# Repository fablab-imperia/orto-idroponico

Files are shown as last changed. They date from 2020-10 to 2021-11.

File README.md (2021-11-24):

# Orto idroponico
> Sistema di controllo per coltivazione idroponica che consente circolazione dell'acqua e parziale correzione dei valori di PH e conducibilità della stessa.

*Read this in other languages: [English :uk: :us:](README.EN.md).*

# Sommario
- [Componenti](#componenti)
- [Schema di Montaggio](#schema-di-montaggio)
- [Configurazione](#configurazione-e-calibrazione)
- [Compilazione del Software](#compilazione-del-software)
  - [Arduino IDE](#arduino-ide)
  - [Visual Studio Code e PlatformIO](#visual-studio-code-e-platformio)
- [Utilizzo e Interfaccia Grafica](#utilizzo-e-interfaccia-grafica)
- [Licenza](#licenza)

# Componenti
Struttura e pompe:
- x2 pompe peristaltiche 12V DC (per fertilizzante e acido)
- Pompa di ricircolo dell'acqua 230V AC (ad esempio per acquari)
- Tubi PVC e raccordi
- Scatola di derivazione (sufficientemente grande da proteggere l'intera elettronica)
- Struttura di sostegno, contenitori per acqua, acido e fertilizzante
- Eventuale interruttore generale

Elettronica:
- ESP32 NodeMCU Development Board
- Sonda pH e relativo modulo
- Sensore Temperatura DS18B20 e relativo modulo
- Sensore Conducibilità e relativo modulo
- LM2596 convertitore step-down
- Display LCD I2C 4x20 caratteri
- Convertitore di livelli logici bidirezionale
- Adafruit ADC ADS1115 (compatibile anche con ADS1015*)
- Modulo con due Relé a Stato Solido
- Modulo singolo Relé a Stato Solido HY-M285
- x2 transistor BC337-40 (o equivalenti)
- x2 resistori 680 Ω
- Alimentatore 12V DC
- PCB o altra soluzione di montaggio (es millefori)

*È necessario definire il tipo di ADC utilizzato nel file [/orto-controller-web/parameters.hpp](/orto-controller-web/parameters.hpp#L30)

Possono essere necessari anche altri componenti (cavi, viti...) e strumenti (trapano, saldatore...) utili alla realizzazione del progetto.

# Schema di Montaggio

I collegamenti ai pin sono definiti nel file `pinouts.hpp` e possono essere modificati opportunamente (prestando attenzione a non utilizzare impropriamente i pin riservati o con funzioni particolari, si veda il [pinout della scheda](https://raw.githubusercontent.com/fablab-imperia/orto-idroponico/main/pinouts/esp32-az-delivery.jpg) per i dettagli).

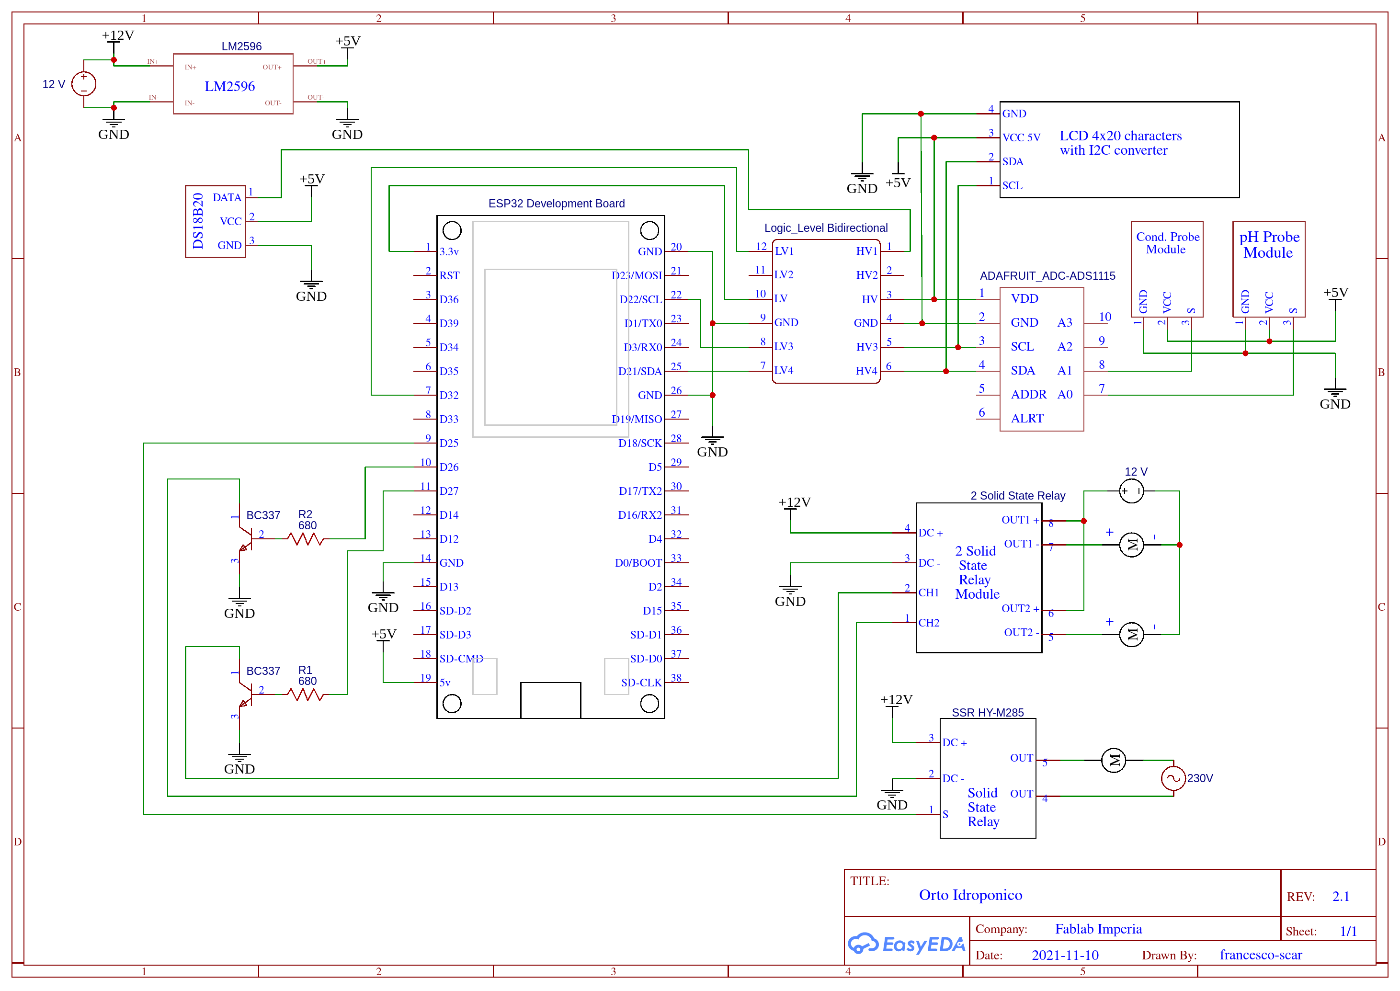
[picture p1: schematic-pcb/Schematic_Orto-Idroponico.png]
alt Orto Idroponico Schematic


# Configurazione e Calibrazione

Prima di procedere con la compilazione del software è necessario assegnare a `condCalibrationPoints[]` e `phCalibrationPoints[]` i valori per la calibrazione dei sensori.

Inoltre è possibile modificare i parametri principali dal file [parameters.hpp](https://github.com/fablab-imperia/orto-idroponico/blob/main/orto-controller-web/parameters.hpp) e i collegamenti con i pin della scheda dal file [pinouts.hpp](https://github.com/fablab-imperia/orto-idroponico/blob/main/orto-controller-web/pinouts.hpp)

# Compilazione del Software

## Arduino IDE

Per procedere con la compilazione mediante Arduino IDE è possibile procedere con i seguenti passaggi:
1. Installazione dell'[IDE di Arduino](https://www.arduino.cc/en/software)

2. Clonazione del repository
```
git clone https://github.com/fablab-imperia/orto-idroponico.git
```
3. Installazione delle dipendenze tramite Arduino Library Manager (selezionare *Sketch > Gestione Librerie* ) oppure scaricando i file zip dal sito di ogni libreria oppure copiando le librerie della cartella [libraries](https://github.com/fablab-imperia/orto-idroponico/tree/main/libraries):
  * [DallasTemperature](https://www.milesburton.com/Dallas_Temperature_Control_Library)
  * [OneWire](http://www.pjrc.com/teensy/td_libs_OneWire.html)
  * [LiquidCrystal I2C](https://github.com/marcoschwartz/LiquidCrystal_I2C)
  * [ArduinoJson](https://github.com/bblanchon/ArduinoJson)
  * [ESPAsyncWebServer](https://github.com/me-no-dev/ESPAsyncWebServer)
  * [AsyncTCP](https://github.com/me-no-dev/AsyncTCP)
  * [Adafruit_ADS1X15](https://github.com/adafruit/Adafruit_ADS1X15)

4. Installazione della scheda ESP32 nell'IDE:
   - a. Da *File > Preferenze > URL Gestore Schede Aggiuntive* aggiungere ```https://dl.espressif.com/dl/package_esp32_index.json```
   - b. Da *Strumenti > Schede > Gestore Schede* cercare ESP32 e installare la relativa scheda
   - c. Selezionare *ESP32 Dev Module* da *Strumenti > Schede*

5. Installare [ESP32 FS-plugin](https://github.com/me-no-dev/arduino-esp32fs-plugin) nell'ide di Arduino

6. Aprire il file [orto-controller-web/orto-controller-web.ino](https://github.com/fablab-imperia/orto-idroponico/blob/main/orto-controller-web/orto-controller-web.ino) nell'IDE di Arduino

7. Avviare la compilazione e caricare il programma sulla scheda (assicurarsi di aver selezionato la scheda e la porta seriale corretta dal menu *Strumenti*)

8. Caricare i file web sulla scheda da *Strumenti > ESP32 Sketch Data Upload*

## Visual Studio Code e PlatformIO

Per procedere con la compilazione mediante Visual Studio Code:
1. Installare [Visual Studio Code](https://code.visualstudio.com/)
2. Installare l'estensione [Platformio](https://platformio.org/install/ide?install=vscode)
3. Aprire la cartella orto-controller-web
4. Installare le librerie richieste
5. Avviare la compilazione  
6. Caricare i file web sulla scheda

# Utilizzo e Interfaccia Grafica
Dopo aver caricato correttamente il programma e i dati, la scheda crea una rete WiFi con SSID e password specificate [qui](https://github.com/fablab-imperia/orto-idroponico/blob/main/orto-controller-web/parameters.hpp#L22) (di default SSID `OrtoWeb` e password `OrtoWeb12345`).
Collegarsi con le credenziali corrette alla rete WiFi e, tramite un browser (es. Firefox, Chrome), connettersi all'indirizzo IP della scheda, stampato all'avvio sul monitor seriale (di default `192.168.4.1`).

Verrà visualizzata la seguente interfaccia grafica.

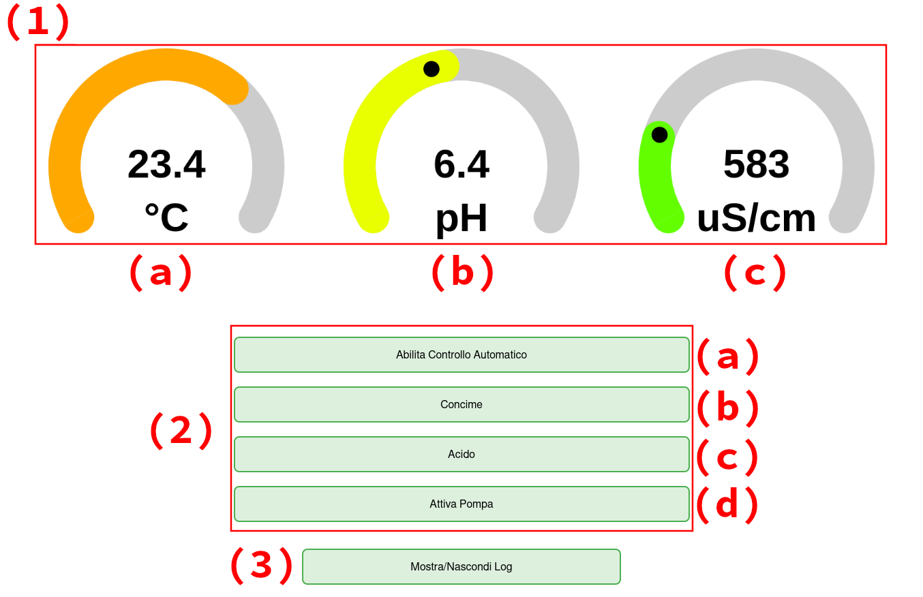
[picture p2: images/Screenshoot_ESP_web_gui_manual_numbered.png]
alt Manual Control Interface


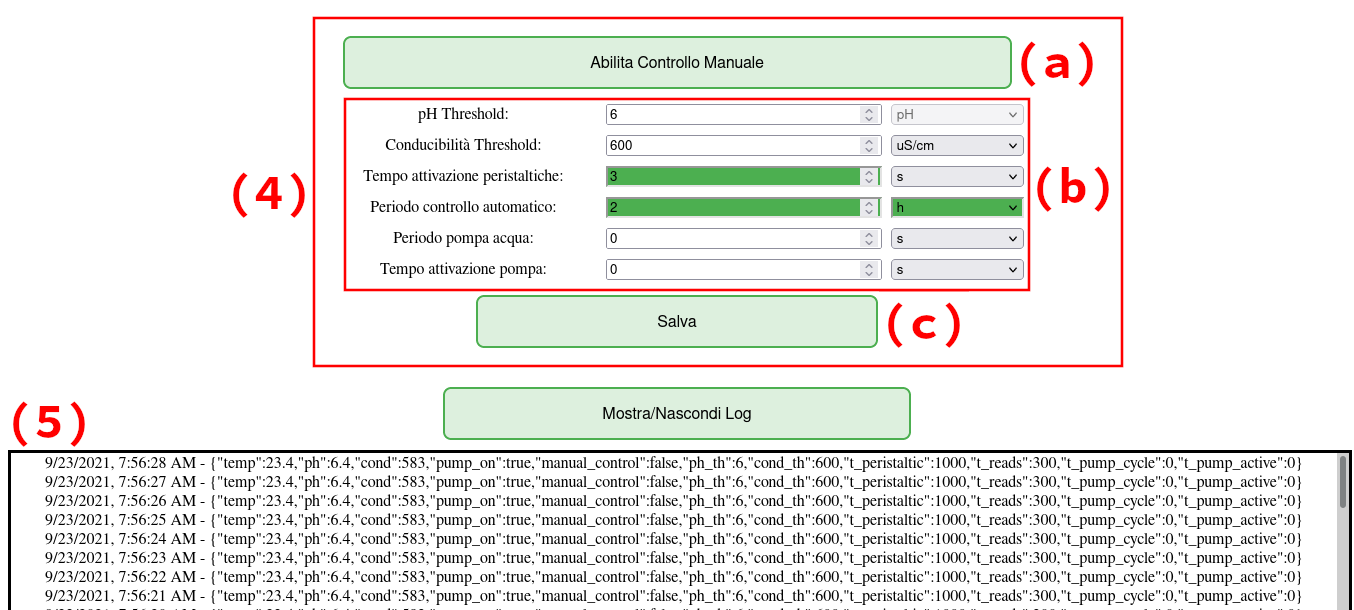
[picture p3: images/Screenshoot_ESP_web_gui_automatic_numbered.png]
alt Automatic Control Interface


L'interfaccia è composta dei seguenti elementi:

1. Indicatore sensori (i pallini neri negli indicatori *b* e *c* indicano il target attualmente impostato), il range dell'indicatore è impostato [qui](https://github.com/fablab-imperia/orto-idroponico/blob/main/orto-controller-web/data/main.js#L18) con i parametri *min* e *max*:
   * a. Temperatura dell'acqua (range indicatore: 0-35 °C)
   * b. pH dell'acqua (range indicatore: 0-14)
   * c. Conducibilita dell'acqua (range indicatore: 0-3000 uS/cm)

2. Pannello di controllo manuale (attivabile con pulsante 4.a)
   * a. Pulsante per abilitare il controllo automatico con i parametri definiti alla sezione (4); alla pressione questa sezione viene sostituita dalla sezione (4)
   * b. Attiva manualmente la pompa peristaltica del concime per la durata della pressione del pulsante (interrompe l'erogazione appena si rilascia il bottone)
   * c. Attiva manualmente la pompa peristaltica dell'acido (per la correzione del pH) per la durata della pressione del pulsante (interrompe l'erogazione appena si rilascia il bottone)
   * d. Attiva/Disattiva la pompa per il ricircolo dell'acqua, alla pressione commuta il suo stato e la sua funzione (da Attiva a Disattiva e viceversa)

3. Mostra o Nasconde i dati grezzi ricevuti dalla scheda, mostrati nella sezione (5) (di default sono nascosti)

4. Pannello di controllo automatico (attivabile con pulsante 2.a)
   * a. Pulsante per abilitare il controllo manuale, sospendento la correzione automatica di fertilizzante e pH e spegnendo la pompa di ricircolo; alla pressione questa sezione viene sostituita dalla sezione (2)
   * b. Parametri di configurazione del controllo automatico:
     * a. valore target del pH
     * b. valore target della conducibilità
     * c. durata di attivazione delle pompe di fertilizzante e acido in caso di correzione dei valori
     * d. tempo che intercorre tra due controlli e correzioni (attivazione pompe peristaltiche) successive
     * e. durata ciclo periodico di ricircolo dell'acqua (se posto a 0 la pompa sarà sempre attiva e il parametro *f* verrà ignorato)
     * f. tempo di attivazione della pompa per il ricircolo dell'acqua in ogni periodo definito al punto *e*
   * c. Il pulsante è normalmente disabilitato, viene attivato automaticamente quando si modifica uno o più dei precedenti parameteri (i parametri modificati vengono evidenziati in verde). Le modifiche dei parametri hanno effetto solo dopo il salvataggio. I dati salvati vengono mantenuti anche dopo lo spegnimento, perché memorizzati nella memoria EEPROM del controllore.

5. Log dei dati grezzi ricevuti dall scheda, la visualizzazione può essere abilitata e disabilitata con il pulsante (3)

I dati dei sensori e i parametri di stato (es controllo automatico/manuale, impostazioni salvate, attivazione manuale della pompa) vengono sincronizzati automaticamente in tempo reale su tutti i client connessi alla scheda.

## Licenza
Sistema di gestione orto idroponico Fablab Imperia

Copyright ©2021  Fablab Imperia, Francesco Scarrone, Stefano Semeria, Valerio Pace

This program is free software: you can redistribute it and/or modify
it under the terms of the GNU General Public License as published by
the Free Software Foundation, either version 3 of the License, or
(at your option) any later version.

This program is distributed in the hope that it will be useful,
but WITHOUT ANY WARRANTY; without even the implied warranty of
MERCHANTABILITY or FITNESS FOR A PARTICULAR PURPOSE.  See the
GNU General Public License for more details.

You should have received a copy of the GNU General Public License
along with this program.  If not, see <https://www.gnu.org/licenses/>.

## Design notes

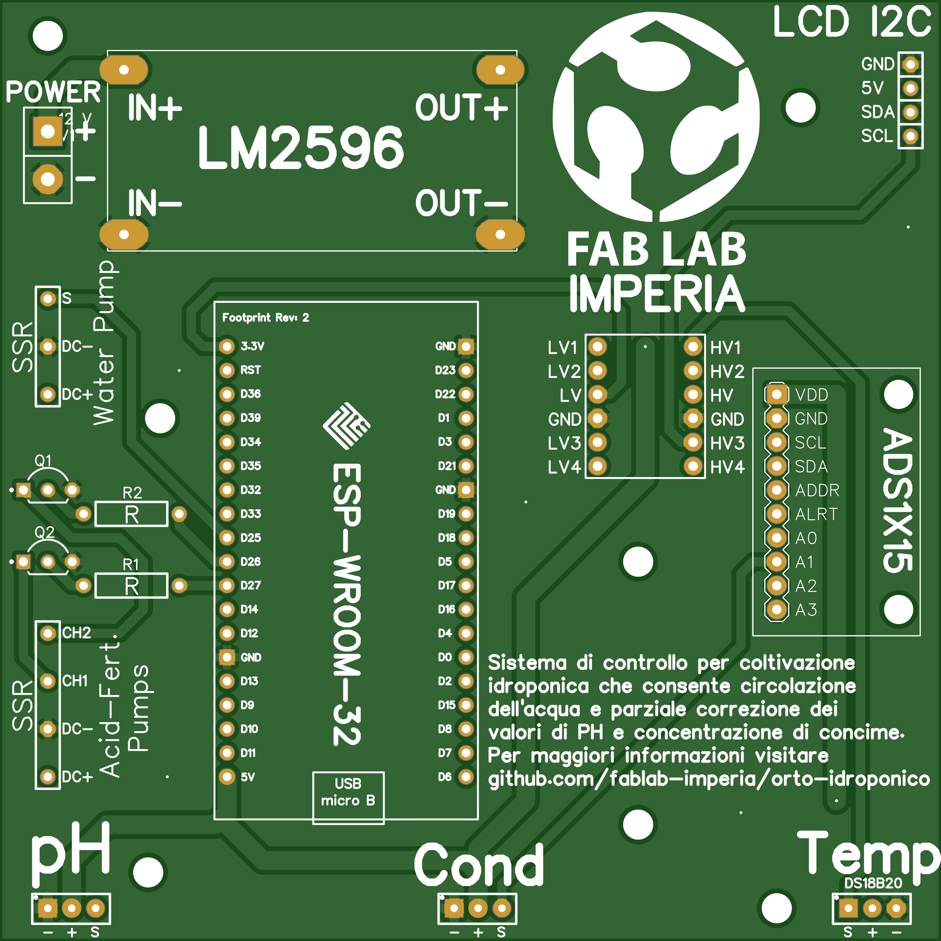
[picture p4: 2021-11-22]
schematic-pcb/PCB_top.png

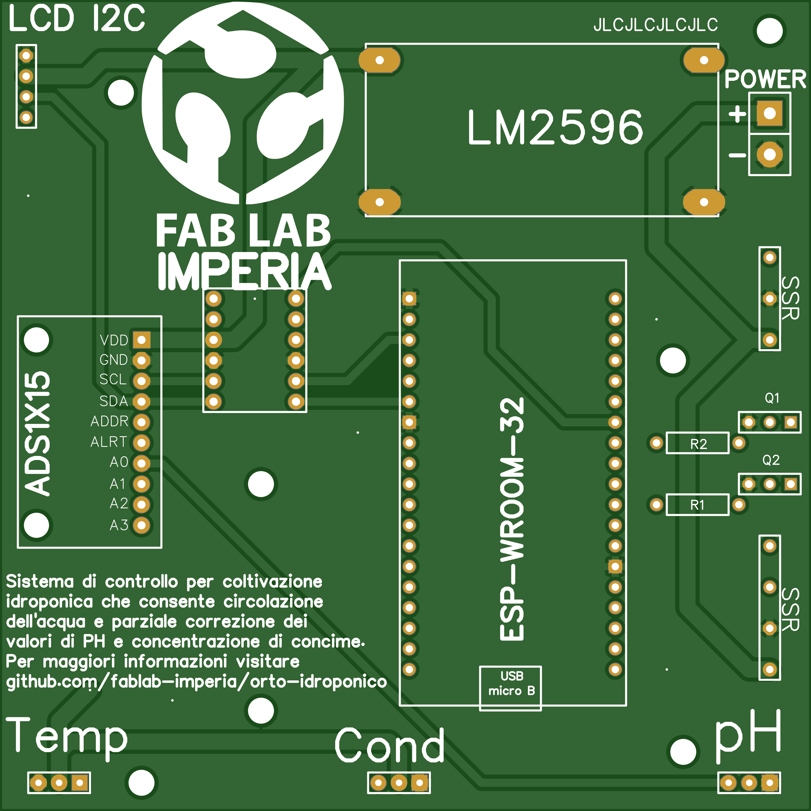
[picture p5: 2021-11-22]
schematic-pcb/PCB_bottom.png

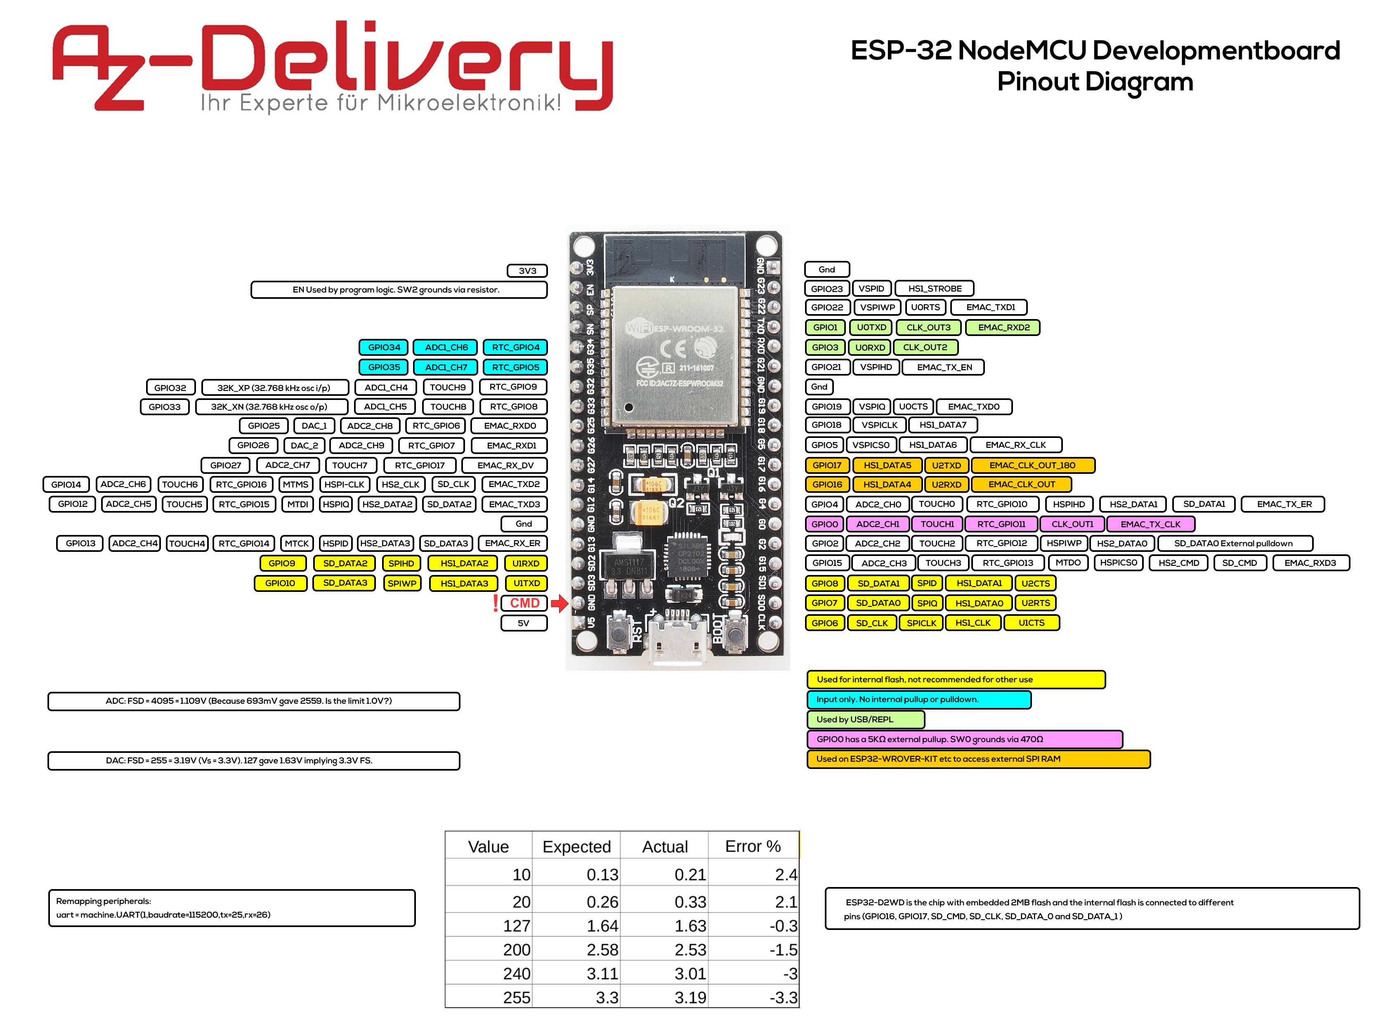
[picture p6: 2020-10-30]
pinouts/esp32-az-delivery.jpg

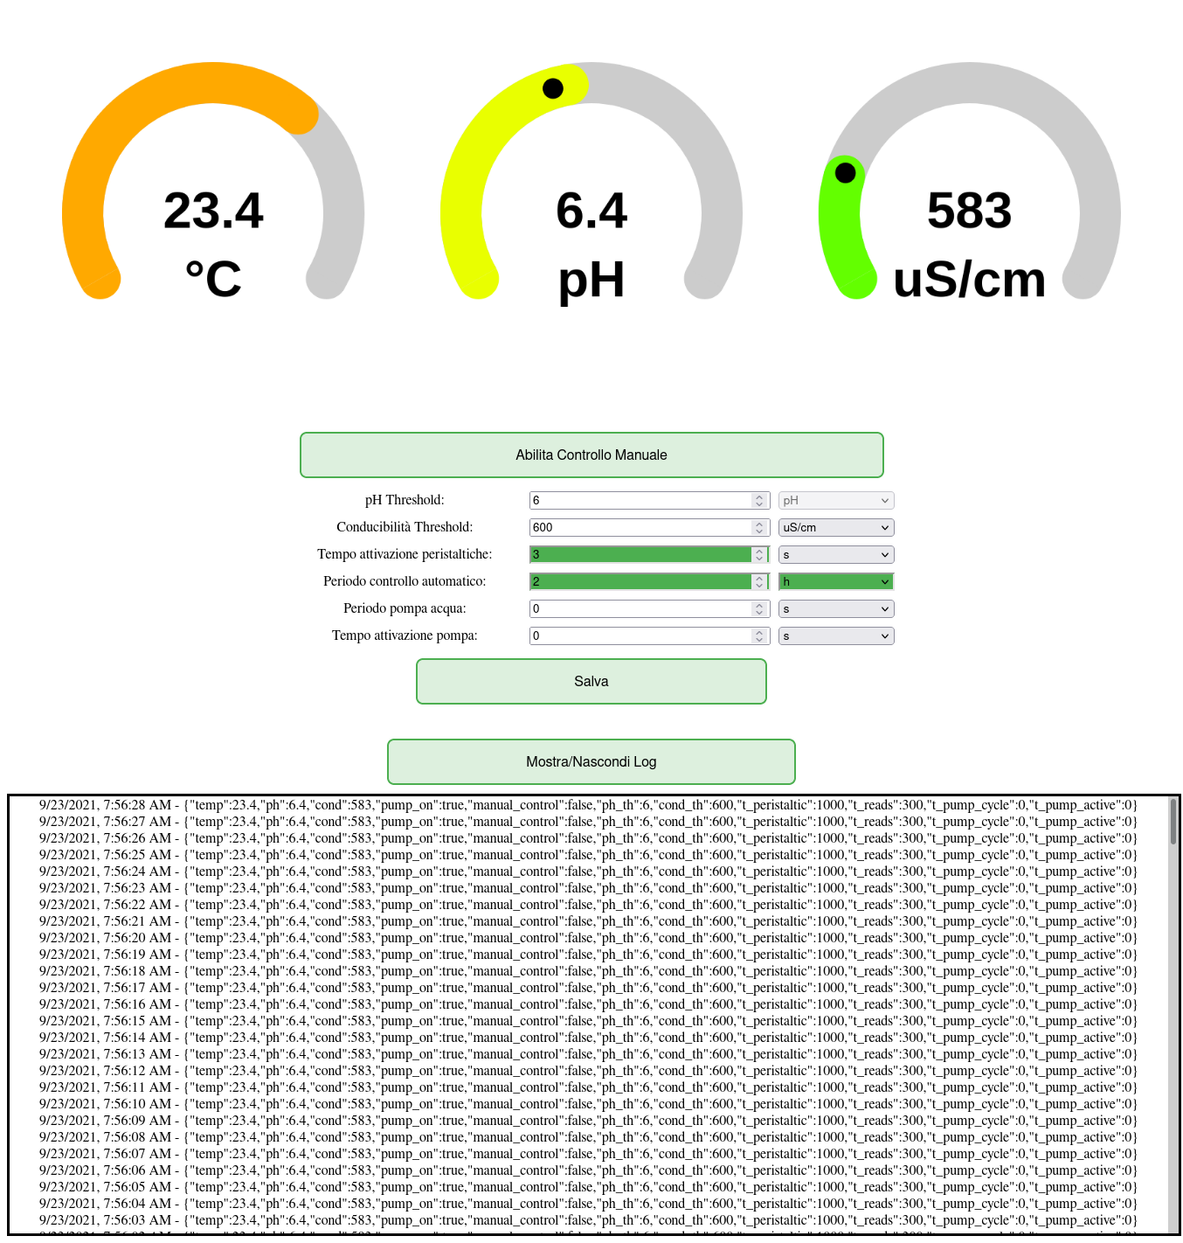
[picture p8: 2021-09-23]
images/Screenshoot_ESP_web_gui_automatic.png

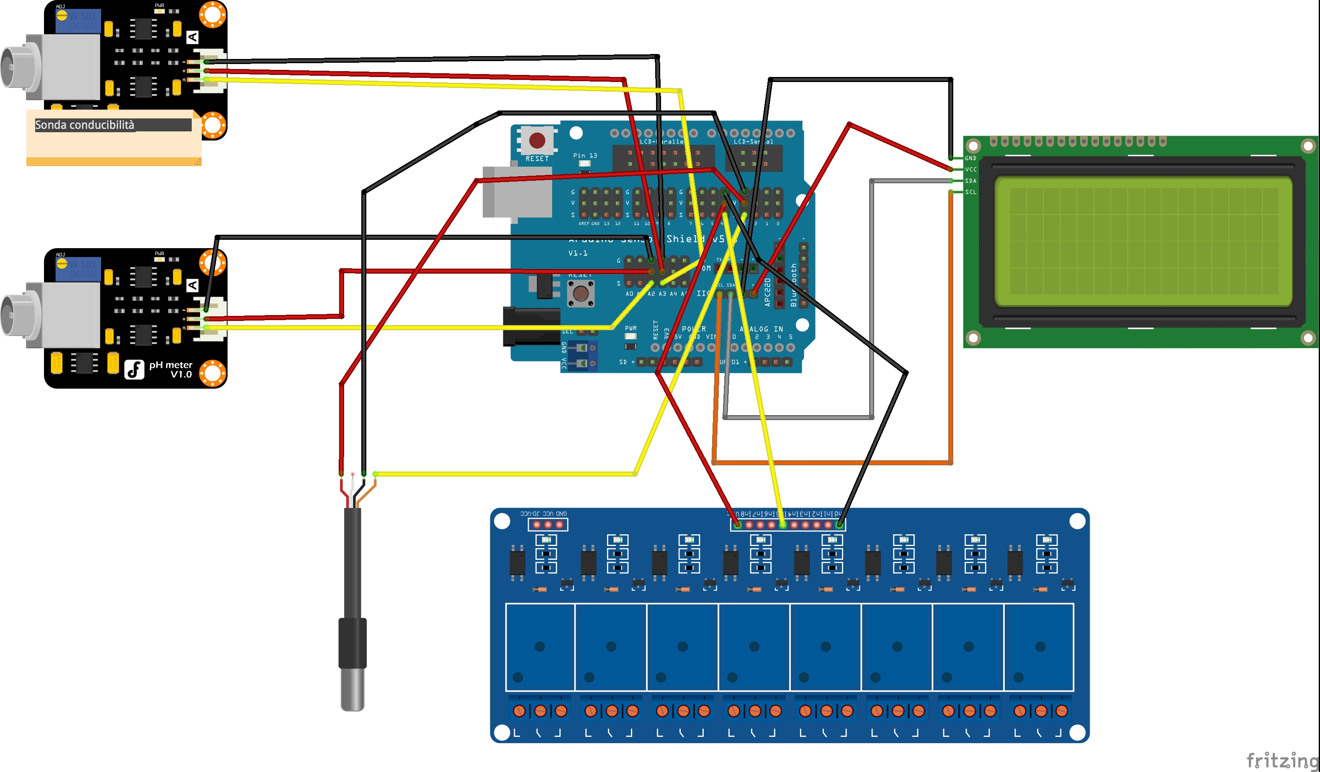
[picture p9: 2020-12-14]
orto-main/frietzing/orto-idroponico_bb.jpg

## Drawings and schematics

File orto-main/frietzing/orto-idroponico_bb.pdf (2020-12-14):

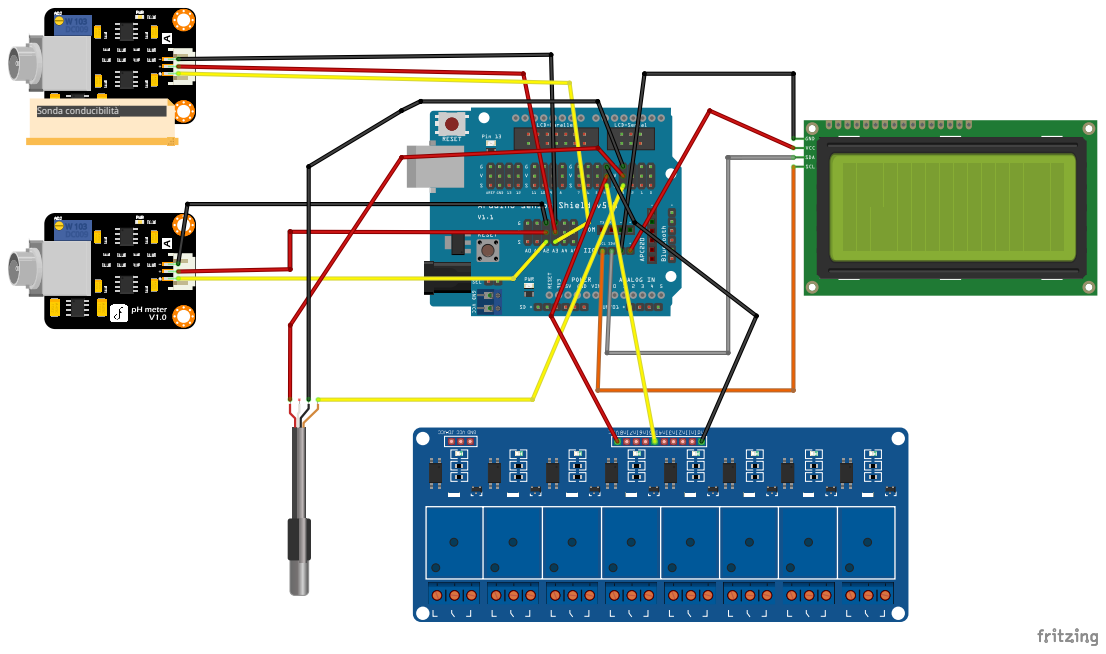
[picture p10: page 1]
Sonda conducibilità

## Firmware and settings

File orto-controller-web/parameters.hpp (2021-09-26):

/*
  This file is part of Orto idroponico Fablab Imperia

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
  You should have received a copy of the GNU General Public License
  along with Nome-Programma.  If not, see <http://www.gnu.org/licenses/>.
*/

// Include for external Adafruit ADC
#include <Adafruit_ADS1X15.h>


#ifndef DEVICE_PARAMETERS
#define DEVICE_PARAMETERS

// WiFi network SSID and PASSWORD
#define ORTO_WEB_SSID_BASENAME "OrtoWeb"
#define ORTO_WEB_SSID_PASSWD "OrtoWeb12345"

// ADC type: define the correct type of ADC (ADS1015 is a 12 bit resolution ADC, ADS1115 is a 16 bit ADC)
//#define ADC_ADS1015
#define ADC_ADS1115

#define LCD_I2C_ADDRESS 0x27
#define LCD_ROWS 4
#define LCD_COLS 20


// Update time of sensors shown in display
#define TIME_BETWEEN_DISPLAY_VALUES 1000

// After MANUAL_CONTROL_PUMP_TIMEOUT ms all pumps will be turned off (without any other command)
#define MANUAL_CONTROL_PERISTALTIC_PUMP_TIMEOUT 500


// Debug serial communication baudrate
#define SERIAL_BAUDRATE 115200







// Usually you don't need to edit the parameters below (if you use the same hardware)


// EEPROM used size, see eeprom.ino
#define EEPROM_USED_SIZE 15


/*  ATTENTION! DEFAULT VALUES ARE DEPRECATED!       *
    Use web interface to set parameters at runtime
    Parameters will be saved into internal EEPROM
    and retrived at startup                         */
// Duration of one water pump cycle in seconds, set to 0 to keep the pump always on
#define DEFAULT_TIME_WATER_PUMP_CYCLE (0)                                               // Put brackets around expressions like (60*60) [1 hour] because of operator precedence
// Time in seconds of water pump activity in a complete cycle (it's ignored if TIME_WATER_PUMP_CYCLE is zero)
#define DEFAULT_TIME_WATER_PUMP_ACTIVE 15                                               // Put brackets around expressions like (60*60) [1 hour] because of operator precedence

//Time the acid and fertilizer pumps remain ON acter activation in ms
#define DEFAULT_TIME_PERISTALTIC_PUMP_ON 1*1000L
//Time in seconds between two consecutives sensor reads. If the value is below/up the the threshold the pump is acivated (acid or fertlizer)
#define DEFAULT_TIME_BETWEEN_SENSOR_READS 60

//PH Threshold vale (if sensor value is higher, acid pump turns ON)
#define DEFAULT_THRESHOLD_VALUE_PH 6
//PH Threshold vale (if  value is higher, acid pump turns ON)
#define DEFAULT_THRESHOLD_VALUE_CONDUCTIVITY 900



#ifdef ADC_ADS1015
#define ADC_MAX_VALUES 2047     // 2^(12-1) - 1
#elif defined(ADC_ADS1115)
#define ADC_MAX_VALUES 32767    // 2^(16-1) - 1
#endif
#define ADC_MAX_VOLTAGE 6.144

#ifdef ADC_ADS1115
#define ADAFRUIT_ADC Adafruit_ADS1115
#elif defined(ADC_ADS1015)
#define ADAFRUIT_ADC Adafruit_ADS1015
#else
#error "No ADC type definition, define the used type in parameters.hpp (https://github.com/fablab-imperia/orto-idroponico)";
#endif*/

#endif

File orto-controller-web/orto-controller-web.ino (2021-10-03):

/*
  This file is part of Orto idroponico Fablab Imperia

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
  You should have received a copy of the GNU General Public License
  along with Nome-Programma.  If not, see <http://www.gnu.org/licenses/>.
*/

#include <Arduino.h>
#include <WiFi.h>
#include <AsyncTCP.h>
#include <ESPAsyncWebServer.h>
#include <HardwareSerial.h>
#include <ArduinoJson.h>

// Include library to save parameters in EEPROM
#include <EEPROM.h>

//Includes for LCD
#include <Wire.h>
#include <LiquidCrystal_I2C.h>

//Includes for Temperature sensor
#include <OneWire.h>
#include <DallasTemperature.h>


//Includes for our own pin definitions and setups
#include "pinouts.hpp"
#include "parameters.hpp"
#include "analog_probe.hpp"
#include "calibrator.hpp"
#include "relay.hpp"
#include "banner.hpp"


// Filesystem for web page files
#define FORMAT_FILESYSTEM false
#include <SPIFFS.h>

// Create AsyncWebServer object on port 80
AsyncWebServer server(80);
AsyncWebSocket ws("/ws");

// JSON buffer
StaticJsonDocument<800> doc;


/*************************************************************
   Hardware components
 ************************************************************/

//LCD dislay
LiquidCrystal_I2C lcd(LCD_I2C_ADDRESS, LCD_COLS, LCD_ROWS);

//Temperature sensor
OneWire oneWire(PIN_TEMPERATURE);
DallasTemperature temperatureSensor(&oneWire);


ADAFRUIT_ADC adc;

//PH sensor
AnalogProbe phProbe(CHANNEL_PH_PROBE, 10);

//Conductivity sensor
AnalogProbe conductivityProbe(CHANNEL_CONDUCTIVITY_PROBE, 10);

// Main water pump
Relay waterPump(PIN_MAIN_WATER_PUMP);

// Peristaltic pumps
Relay fertilizerPump = Relay(PIN_PERISTALTIC_PUMP_FERTILIZER);
Relay acidPump = Relay(PIN_PERISTALTIC_PUMP_ACID);


/*************************************************************
   Scheduling and tasks declarations
 ************************************************************/

//TIMER
unsigned long lastswitch = 0;
unsigned long lastcontrol = 0;
unsigned long lastping = 0;
unsigned long lastdisplay = 0;

// Manual or automatic control state
bool manual_control = false;
bool manual_peristaltic_active = false;

// Parameters
float threshold_value_ph = DEFAULT_THRESHOLD_VALUE_PH;                          // pH
int threshold_value_conductivity = DEFAULT_THRESHOLD_VALUE_CONDUCTIVITY;        // uS/cm (?)
unsigned int time_peristaltic_pump_on = DEFAULT_TIME_PERISTALTIC_PUMP_ON;       // ms
unsigned long time_between_sensor_reads = DEFAULT_TIME_BETWEEN_SENSOR_READS;    // s
unsigned long time_water_pump_cycle = DEFAULT_TIME_WATER_PUMP_CYCLE;            // s
unsigned long time_water_pump_active = DEFAULT_TIME_WATER_PUMP_ACTIVE;          // s


void setup() {
  // Serial port for debugging purposes
  Serial.begin(SERIAL_BAUDRATE);
  Serial.println("Starting...");
  Banner::printSerial();

  EEPROM.begin(EEPROM_USED_SIZE);

  //XYPair phCalibrationPoints[] = {{1.80f, 6.88f}, {1.46f, 4.00f,}, {2.13f, 9.23f}};//stefano
  XYPair phCalibrationPoints[] = {{1.51f, 4.01f,}, {1.86f, 7.00f}, {2.08f, 8.80f}, {2.23f, 10.01f,}};//Vale
  //LineFit phBestFit = Calibrator::findBestFit(phCalibrationPoints, 3);//Stefano
  LineFit phBestFit = Calibrator::findBestFit(phCalibrationPoints, 4);//vale

  XYPair condCalibrationPoints[] = {{ 0.2f, 220.0f}, { 0.6f, 564.0f}, { 0.0f, 68.0f}};
  LineFit condBestFit = Calibrator::findBestFit(condCalibrationPoints, 3);

  phProbe.initProbe(phBestFit);
  conductivityProbe.initProbe(condBestFit);

  lcd.init();
  lcd.backlight();
  temperatureSensor.begin();
  waterPump.init();
  fertilizerPump.init();
  acidPump.init();

  adc.begin(0x48);              // Initialize ADC at the default address 0x48 (address can be setted with ADR pin: https://learn.adafruit.com/adafruit-4-channel-adc-breakouts/assembly-and-wiring#i2c-addressing-2974117-12)
  adc.setGain(GAIN_TWOTHIRDS);  // 2/3x gain +/- 6.144V  1 bit = 3mV (default)

  retrive_configuration();

  // Stops all pumps at beginning
  acidPump.turnOff();
  fertilizerPump.turnOff();
  waterPump.turnOff();


  WiFi.softAP(ORTO_WEB_SSID_BASENAME, ORTO_WEB_SSID_PASSWD);

  IPAddress IP = WiFi.softAPIP();
  Serial.print("AP IP address: ");
  Serial.println(IP);

  fs_web_init();

}

void loop() {
  ws.cleanupClients();

  if (millis() - lastdisplay >= TIME_BETWEEN_DISPLAY_VALUES && !manual_peristaltic_active) {
    readAndShowSensorValues();
  }



  if (manual_control) {
    unsigned long t = millis();
    if ((t - lastping) > MANUAL_CONTROL_PERISTALTIC_PUMP_TIMEOUT && t >= lastping && manual_peristaltic_active) {
      acidPump.turnOff();
      fertilizerPump.turnOff();
      manual_peristaltic_active = false;
      Serial.print("Turning off peristaltic pumps: no ping received in ");
      Serial.print(MANUAL_CONTROL_PERISTALTIC_PUMP_TIMEOUT);
      Serial.print(" ms -  ");
      Serial.print(t);
      Serial.print("  -  ");
      Serial.println(lastping);
    }
  } else {
    if ((millis() - lastcontrol) / 1000 >= time_between_sensor_reads) {
      readSensorsAndStartPumps();
    }
    if (time_water_pump_cycle) {
      if ((millis() / 1000 % time_water_pump_cycle) < time_water_pump_active) {
        waterPump.turnOn();
      } else {
        waterPump.turnOff();
      }
    } else {
      waterPump.turnOn();
    }
  }
}

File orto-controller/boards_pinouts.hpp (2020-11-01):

#ifndef BOARDS_PARAMETERS_H
#define BOARDS_PARAMETERS_H


#if defined(__AVR_ATmega168__) || defined(__AVR_ATmega328P__)
// PINOUTS FOR ARDUINO UNO
#define PIN_I2C_SDA 18
#define PIN_I2C_SCL 19
#define PIN_LED  13
#define PIN_TEMPERATURE 3
#define PIN_PH_PROBE A2
#define PIN_CONDUCTIVITY_PROBE A3
//Baudrate 
#define SERIAL_BAUDRATE 9600
//SPECS
#define ADC_MAX_VALUES 1024
#define ADC_MAX_VOLTAGE 5
#else 
// PINOUTS FOR ESP32
#define PIN_I2C_SDA 21
#define PIN_I2C_SCL 22
#define PIN_LED  1
#define PIN_TEMPERATURE 32
#define PIN_PH_PROBE 20
#define PIN_CONDUCTIVITY_PROBE 23
//Baudrate 
#define SERIAL_BAUDRATE 115200
//SPECS
#define ADC_MAX_VALUES 4096
#define ADC_MAX_VOLTAGE 3.3
#endif

#endif

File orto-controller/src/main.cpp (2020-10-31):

#include <Arduino.h>

//Includes for LCD
#include <Wire.h> 
#include <LiquidCrystal_I2C.h>

//Includes for Temperature sensor
#include <OneWire.h>
#include <DallasTemperature.h>

//Includes for our own pin definitions and setups
#include "boards_pinouts.hpp"
#include "devices_parameters.hpp"
#include "analog_ph_probe.hpp"

//LCD dislay
LiquidCrystal_I2C lcd(LCD_I2C_ADDRESS,LCD_COLS,LCD_ROWS);
OneWire oneWire(PIN_TEMPERATURE);

//Temperature sensor
DallasTemperature temperatureSensor(&oneWire);

//PH sensor
AnalogPhProbe phProbe(PIN_PH_PROBE);

void setup() {
  Serial.begin(SERIAL_BAUDRATE);
  Serial.println("Starting...");

  lcd.init();             
  lcd.backlight();

  temperatureSensor.begin();
}

void loop() {
  temperatureSensor.requestTemperatures(); 
  lcd.clear();
  float temperatureC = temperatureSensor.getTempCByIndex(0);
  Serial.println(phProbe.getAveragePhValue());
  lcd.print(temperatureC);
  delay(2000);
} 

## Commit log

2020-10-24 simple blink sketch for AZ delivery ESP32
2020-10-30 First version with cross platform compilation (ESP32 and Arduino)
2020-10-31 temperature sensor and LCD. Ph in progress
2020-11-01 Progetto ristrutturato in modo da consentire compilaione con Arduino IDE
    [orto-controller.fzz]
2020-11-22 unito analog probe per ph e conduttività
2020-11-22 unito analog probe e aggiunto conduttività
2020-11-26 Aggiunta temperatura. Pretty Print
2020-11-26 refactoring. Classe relays funzionante
2020-12-09 Nuova versione con libreria task per sensori e azionamento pompa
2020-12-14 nuovo schema fritzing
    [orto-controller.fzz, orto-idroponico.fzz]
2020-12-26 test timer
2020-12-26 nuovo timer a ordine lcd
2021-02-20 spostaton codice stampa valori sensori
2021-02-21 nuovo progetto per interfaccia web su ESP32
2021-08-08 commentato un po' di codice per agevolare i test
2021-08-22 Nuova versione semplificata. La pompa è attiva sempre e i valori dei sensori sono letti ogni minuto
2021-08-22 all files in
    [orto-idroponico.fzz]
2021-09-05 :sparkles: ESP32-Arduino serial communication, basic test web GUI...
2021-09-20 :construction: Temp version Arduino-ESP32 (instable)
2021-09-20 :construction: ESP32-only initial integration, web gui and peristaltic pumps control
2021-09-20 :iphone: Fixed buttons in mobile browsers
2021-09-20 :children_crossing: Improve manual control usability, ping parameters and water pump control (automatic and manual)
2021-09-21 :bug: Fixed fertilizer manual bug and sync current status in web gui
    [orto-controller-web.ino, sensors_pump.ino, web.ino]
2021-09-21 :bug: Fixed manual water pump control bug
2021-09-21 :bug: Fixed peristaltic pumps timeout bug (race condition related)
    [orto-controller-web.ino, parameters.hpp, web.ino]
2021-09-22 :lipstick: Changed style and show/hide logs button
2021-09-23 :children_crossing: Add degree symbol in temperature gauge
2021-09-23 :memo: ESP32 data upload and move summary
2021-09-24 :memo: Schematic and image for documentation
2021-09-24 :memo: Schematic and minor changes
2021-09-24 :fire: Removed unused old code
    [orto-idroponico.fzz]
2021-09-26 :sparkles: External Adafruit ADC integration and code indentation
2021-09-26 :memo: Basic configuration and calibration description
2021-09-27 :memo: Update schematic image
2021-09-27 :package: Update schematic project file
2021-10-03 :bug: Error in automatic control timing and fertilizer pump off bug
    [orto-controller-web.ino, sensors_pump.ino]
2021-10-25 :bug: Fixed relay control logic bug (typo) and default values
    [relay.cpp]
2021-11-15 :memo: New schematic
2021-11-22 :package: PCB gerber file
2021-11-22 :memo: PCB gerber render images
